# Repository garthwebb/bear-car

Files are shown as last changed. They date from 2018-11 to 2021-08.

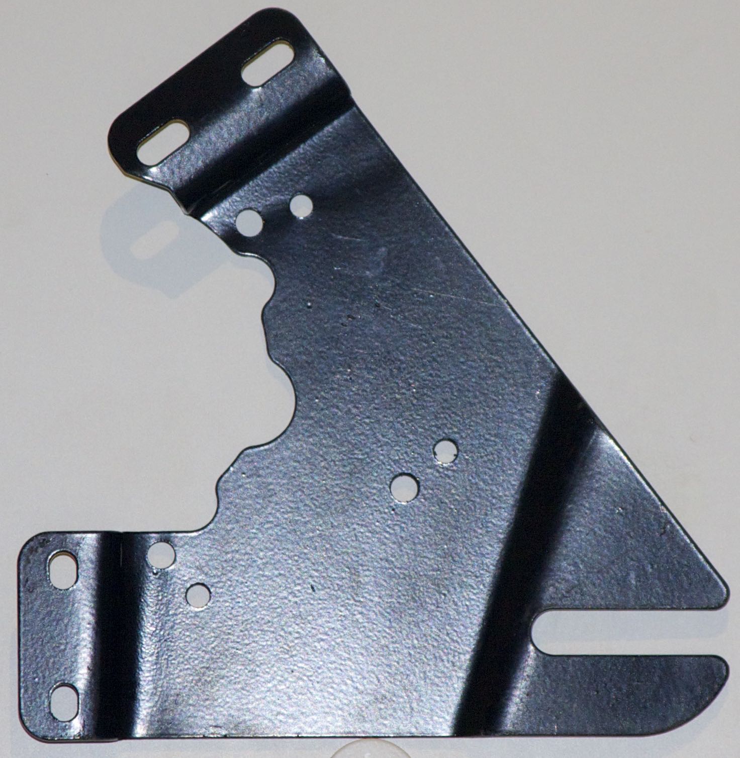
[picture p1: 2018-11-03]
images/IMG_2482.jpg

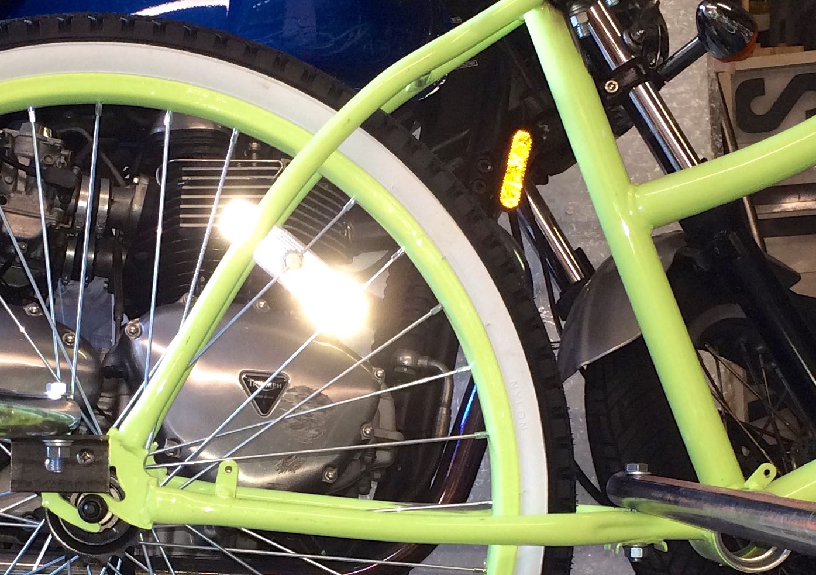
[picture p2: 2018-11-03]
images/IMG_5532.jpg

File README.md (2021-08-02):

# Bear Car

Bear car is an art car project brought to Burning Man in 2015 ([photos](https://photos.app.goo.gl/hQNxJEHgqHZzFq1y2)), meant to look like
[rilakkuma](http://www.san-x.jp/characters/rilakkuma.html), the lazy bear.

It consists of two Huffy beach cruiser bikes that are bolted together.
A linkage in front connects the two bicycles steering columns in an Ackermann steering geometry.  The bicycles are driven by two 350W electric
motors via a chain to the rear wheels.  Two people can ride in the car, who's top speed is around 15mph and can drive for around 2 hours on a charge.

An LED controller connects to a WiFi router that allows an iPhone running [L.E.D Labs](https://apps.apple.com/us/app/l-e-d-lab/id832042156)
to connect and control the dome lights.

bear car

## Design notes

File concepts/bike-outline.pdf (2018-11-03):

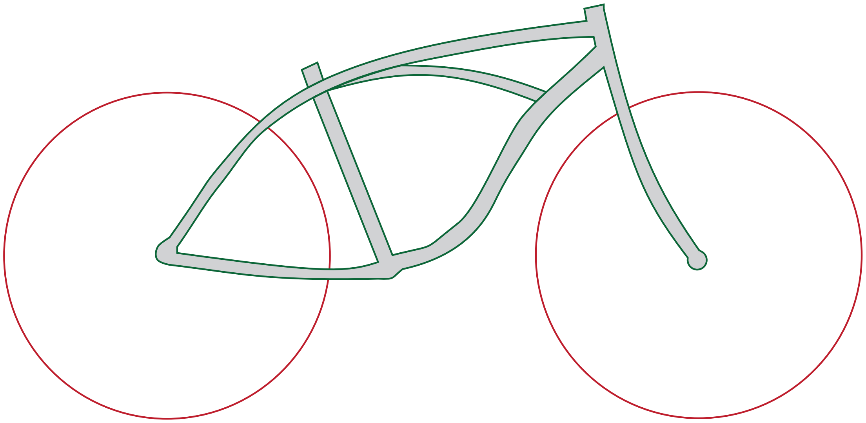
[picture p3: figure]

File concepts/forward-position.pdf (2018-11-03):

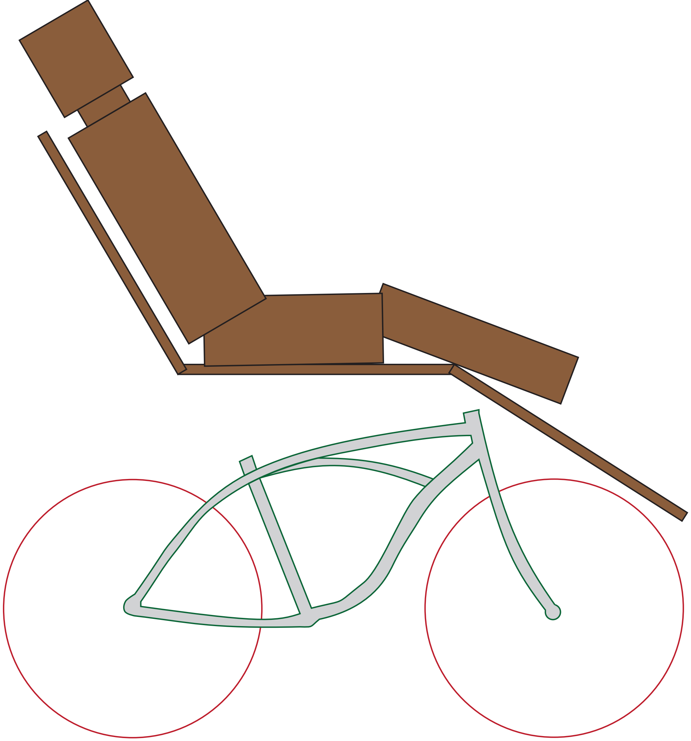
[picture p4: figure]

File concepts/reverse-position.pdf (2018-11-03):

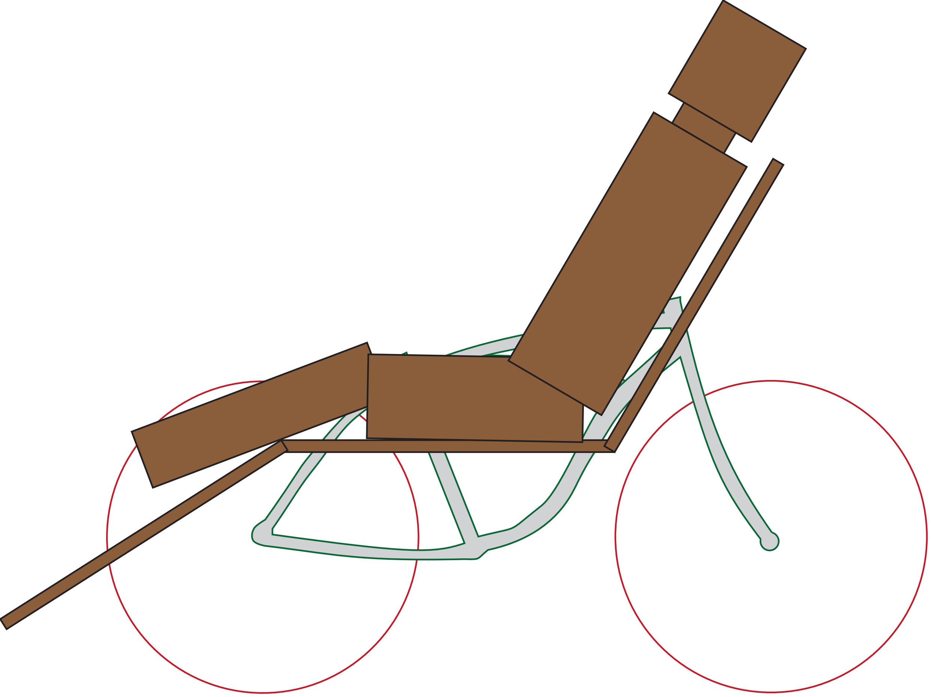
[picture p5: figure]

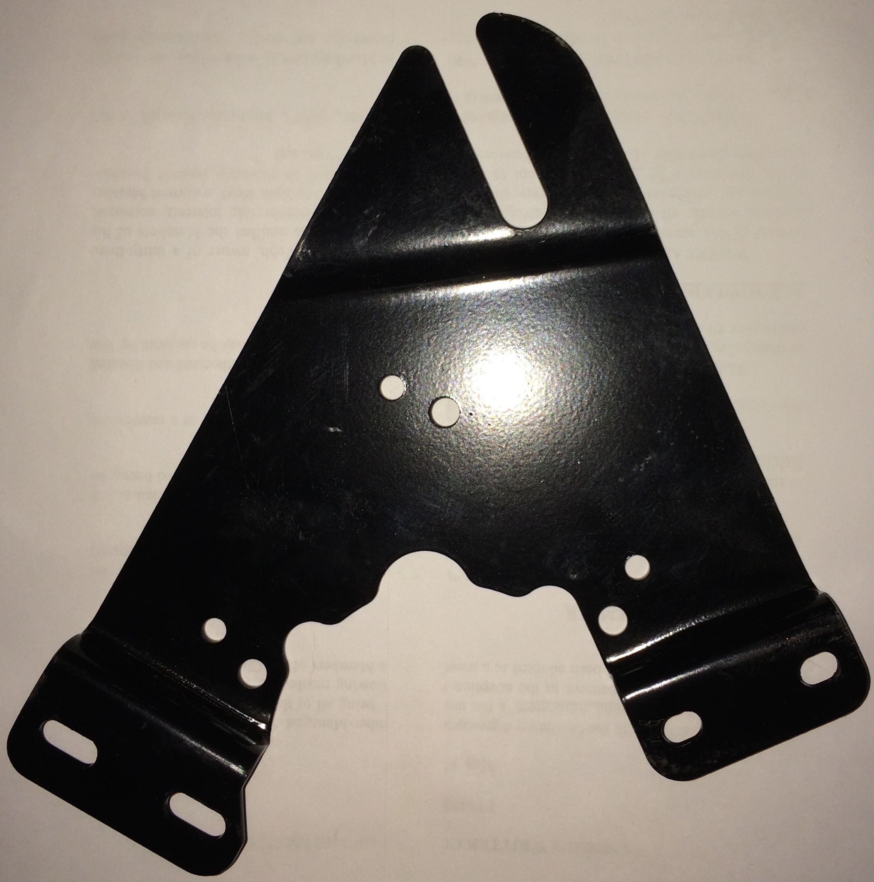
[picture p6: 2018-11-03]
mounting brackets/motor mount.JPG

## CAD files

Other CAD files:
mounting brackets/front fork/Bear Fork Front.dxf
mounting brackets/front fork/Bear Fork Side.dxf
models/Dome.skp
models/Steering Visualization.skp
models/battery holder.skp

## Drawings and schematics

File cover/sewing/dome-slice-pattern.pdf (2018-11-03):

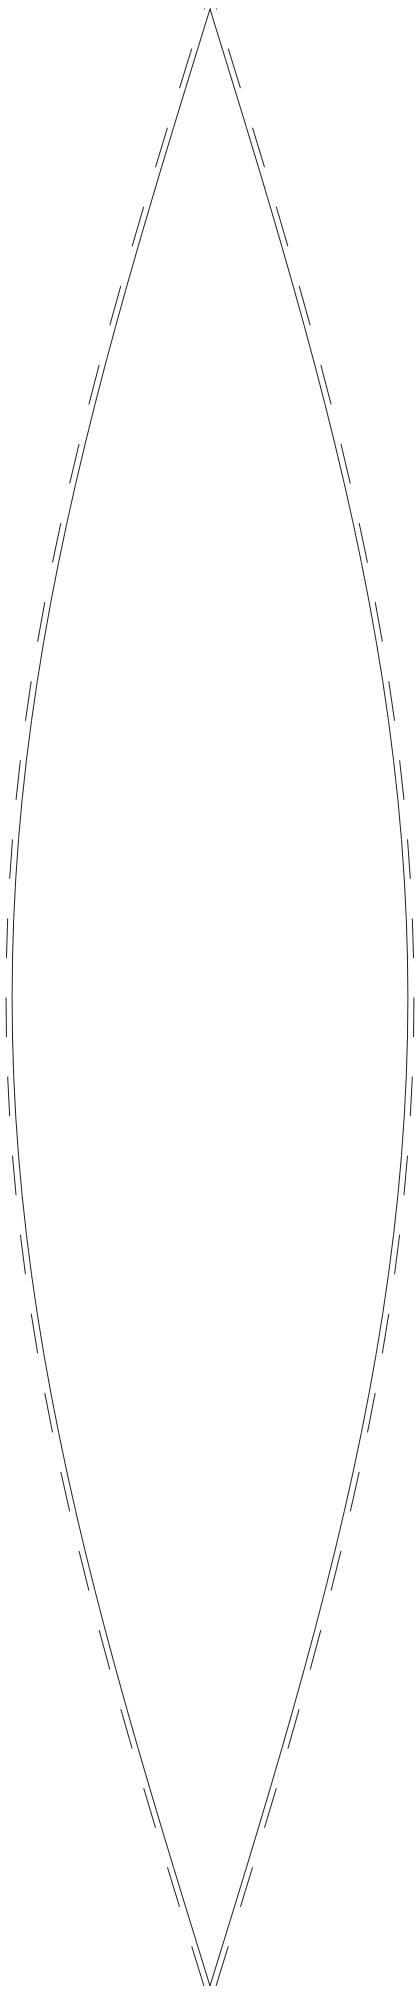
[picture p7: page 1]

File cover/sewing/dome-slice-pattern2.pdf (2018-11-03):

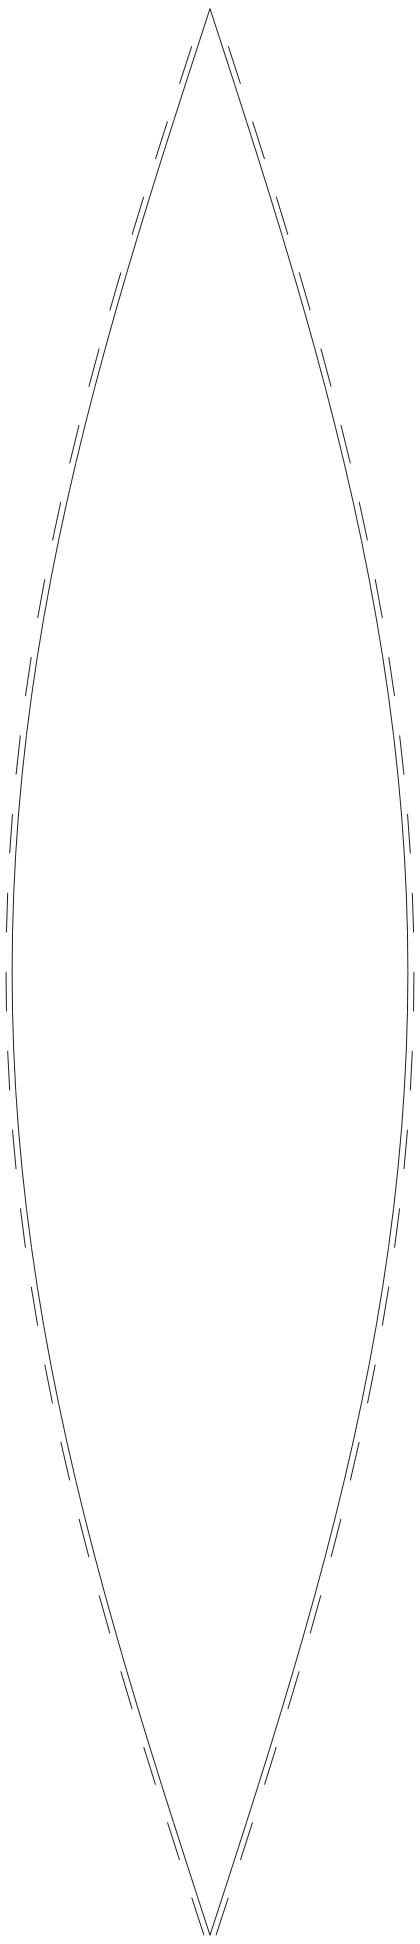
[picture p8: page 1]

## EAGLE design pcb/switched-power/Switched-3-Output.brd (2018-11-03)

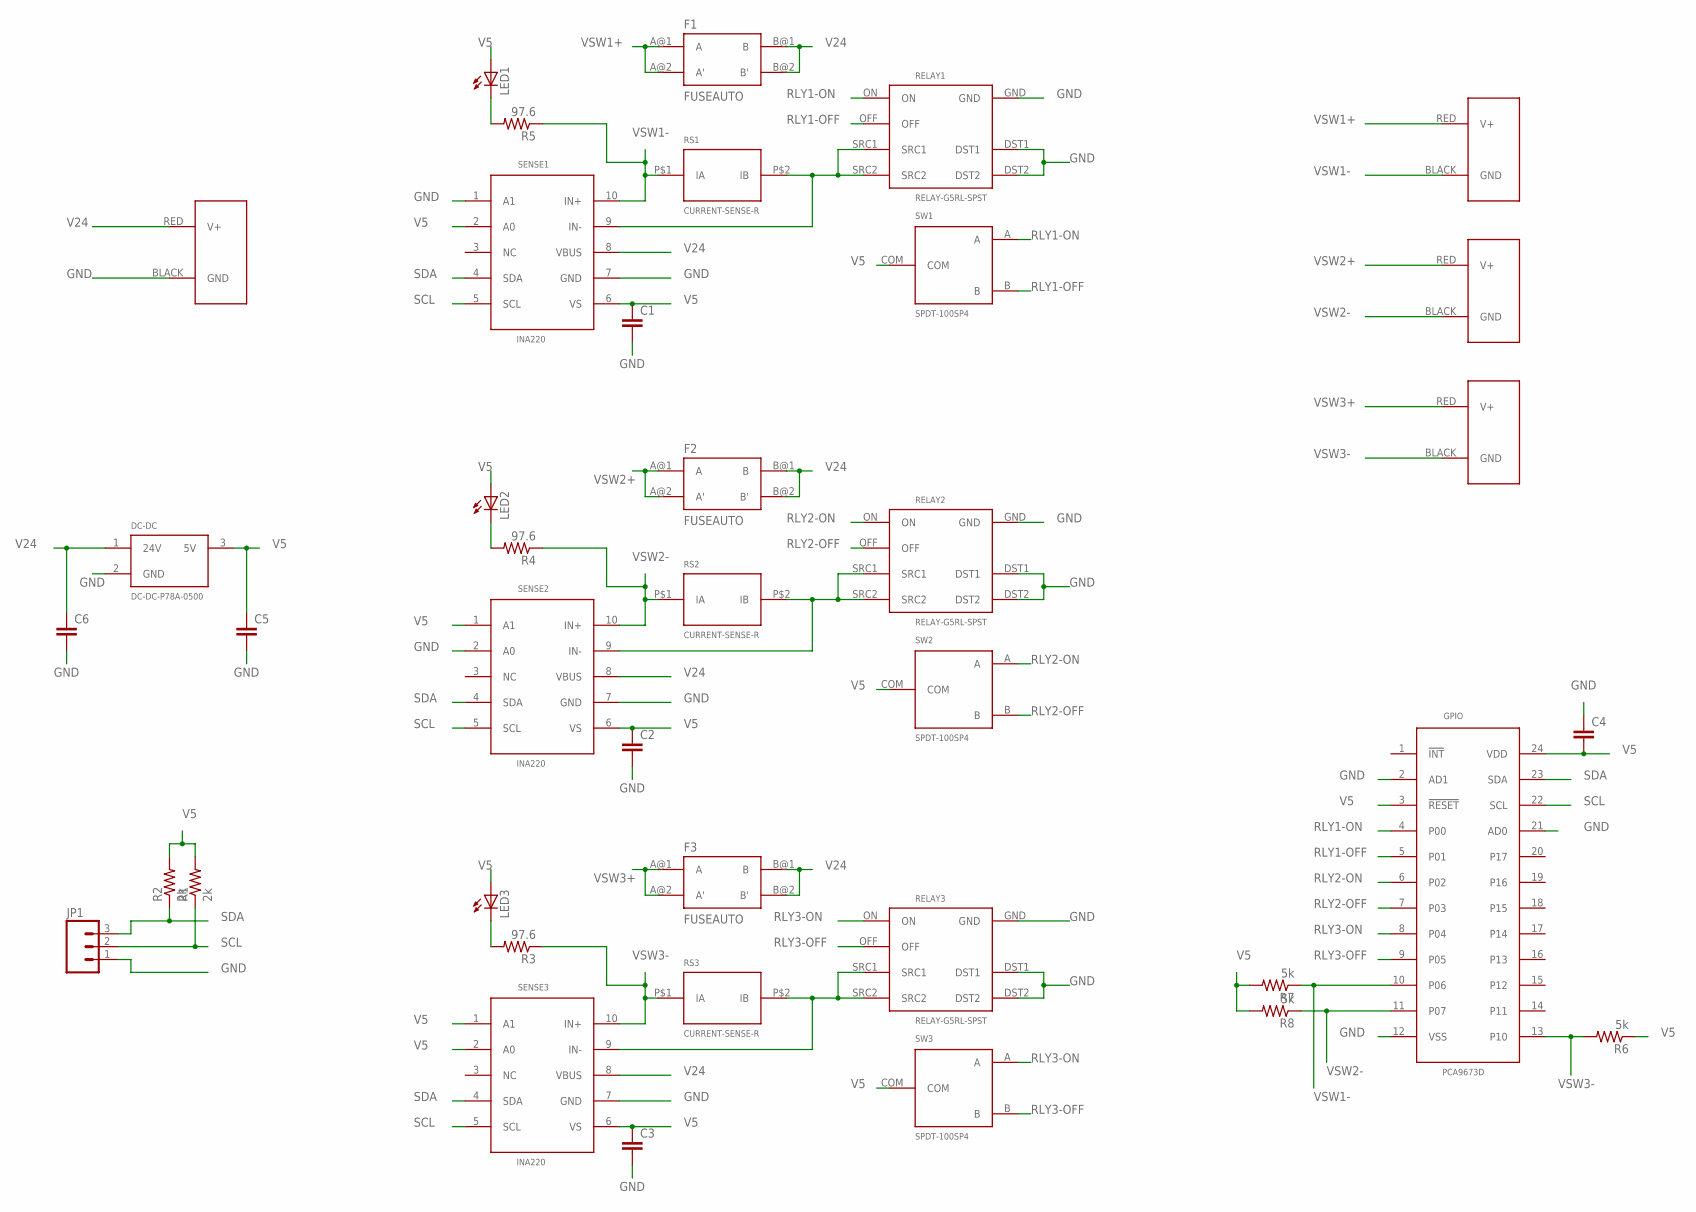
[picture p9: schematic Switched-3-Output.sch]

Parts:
C1, C2, C3, C4, C5, C6: C-EUC0805; C0805
DC-DC: DC-DC-P78A-0500
F1, F2, F3: FUSEAUTO; FUSE
GPIO: PCA9673D; SO24
JP1: M03PTH; 1X03
LED1, LED2, LED3: LED3MM
PWR: POWERPOLE_POWER45A_DRILL; POWERPOLE_PAIR_45A_HOLE
R1, R2: 2k; R0805
R3, R4, R5: 97.6; R0805
R6, R7, R8: 5k; R0805
RELAY1, RELAY2, RELAY3: RELAY-G5RL-SPST
RS1, RS2, RS3: CURRENT-SENSE-R
SENSE1, SENSE2, SENSE3: INA220; SOP-10
SW1, SW2, SW3: SPDT-100SP4
VSW1, VSW2, VSW3: POWERPOLE_POWER45A_DRILL; POWERPOLE_PAIR_45A_HOLE

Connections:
GND: C1.2, C2.2, C3.2, C4.1, C5.2, C6.2, DC-DC.2 (GND), GPIO.2 (AD1), GPIO.12 (VSS), GPIO.21 (AD0), JP1.1, PWR.BLACK (GND), RELAY1.DST1, RELAY1.DST2, RELAY1.GND, RELAY2.DST1, RELAY2.DST2, RELAY2.GND, RELAY3.DST1, RELAY3.DST2, RELAY3.GND, SENSE1.1 (A1), SENSE1.7 (GND), SENSE2.2 (A0), SENSE2.7 (GND), SENSE3.7 (GND)
unnamed: LED1.K (C), R5.2
unnamed: RELAY1.SRC1, RELAY1.SRC2, RS1.P$2 (IB), SENSE1.9 (IN-)
unnamed: RELAY3.SRC1, RELAY3.SRC2, RS3.P$2 (IB), SENSE3.9 (IN-)
unnamed: LED2.K (C), R4.2
unnamed: RELAY2.SRC1, RELAY2.SRC2, RS2.P$2 (IB), SENSE2.9 (IN-)
unnamed: LED3.K (C), R3.2
RLY1-OFF: GPIO.5 (P01), RELAY1.OFF, SW1.B
RLY1-ON: GPIO.4 (P00), RELAY1.ON, SW1.A
RLY2-OFF: GPIO.7 (P03), RELAY2.OFF, SW2.B
RLY2-ON: GPIO.6 (P02), RELAY2.ON, SW2.A
RLY3-OFF: GPIO.9 (P05), RELAY3.OFF, SW3.B
RLY3-ON: GPIO.8 (P04), RELAY3.ON, SW3.A
SCL: GPIO.22 (SCL), JP1.2, R1.1, SENSE1.5 (SCL), SENSE2.5 (SCL), SENSE3.5 (SCL)
SDA: GPIO.23 (SDA), JP1.3, R2.1, SENSE1.4 (SDA), SENSE2.4 (SDA), SENSE3.4 (SDA)
V5: C1.1, C2.1, C3.1, C4.2, C5.1, DC-DC.3 (5V), GPIO.3 (!RESET!), GPIO.24 (VDD), LED1.A, LED2.A, LED3.A, R1.2, R2.2, R6.1, R7.2, R8.2, SENSE1.2 (A0), SENSE1.6 (VS), SENSE2.1 (A1), SENSE2.6 (VS), SENSE3.1 (A1), SENSE3.2 (A0), SENSE3.6 (VS), SW1.COM, SW2.COM, SW3.COM
V24: C6.1, DC-DC.1 (24V), F1.B@1 (B), F1.B@2 (B'), F2.B@1 (B), F2.B@2 (B'), F3.B@1 (B), F3.B@2 (B'), PWR.RED (V+), SENSE1.8 (VBUS), SENSE2.8 (VBUS), SENSE3.8 (VBUS)
VSW1+: F1.A@1 (A), F1.A@2 (A'), VSW1.RED (V+)
VSW1-: GPIO.10 (P06), R5.1, R7.1, RS1.P$1 (IA), SENSE1.10 (IN+), VSW1.BLACK (GND)
VSW2+: F2.A@1 (A), F2.A@2 (A'), VSW2.RED (V+)
VSW2-: GPIO.11 (P07), R4.1, R8.1, RS2.P$1 (IA), SENSE2.10 (IN+), VSW2.BLACK (GND)
VSW3+: F3.A@1 (A), F3.A@2 (A'), VSW3.RED (V+)
VSW3-: GPIO.13 (P10), R3.1, R6.2, RS3.P$1 (IA), SENSE3.10 (IN+), VSW3.BLACK (GND)

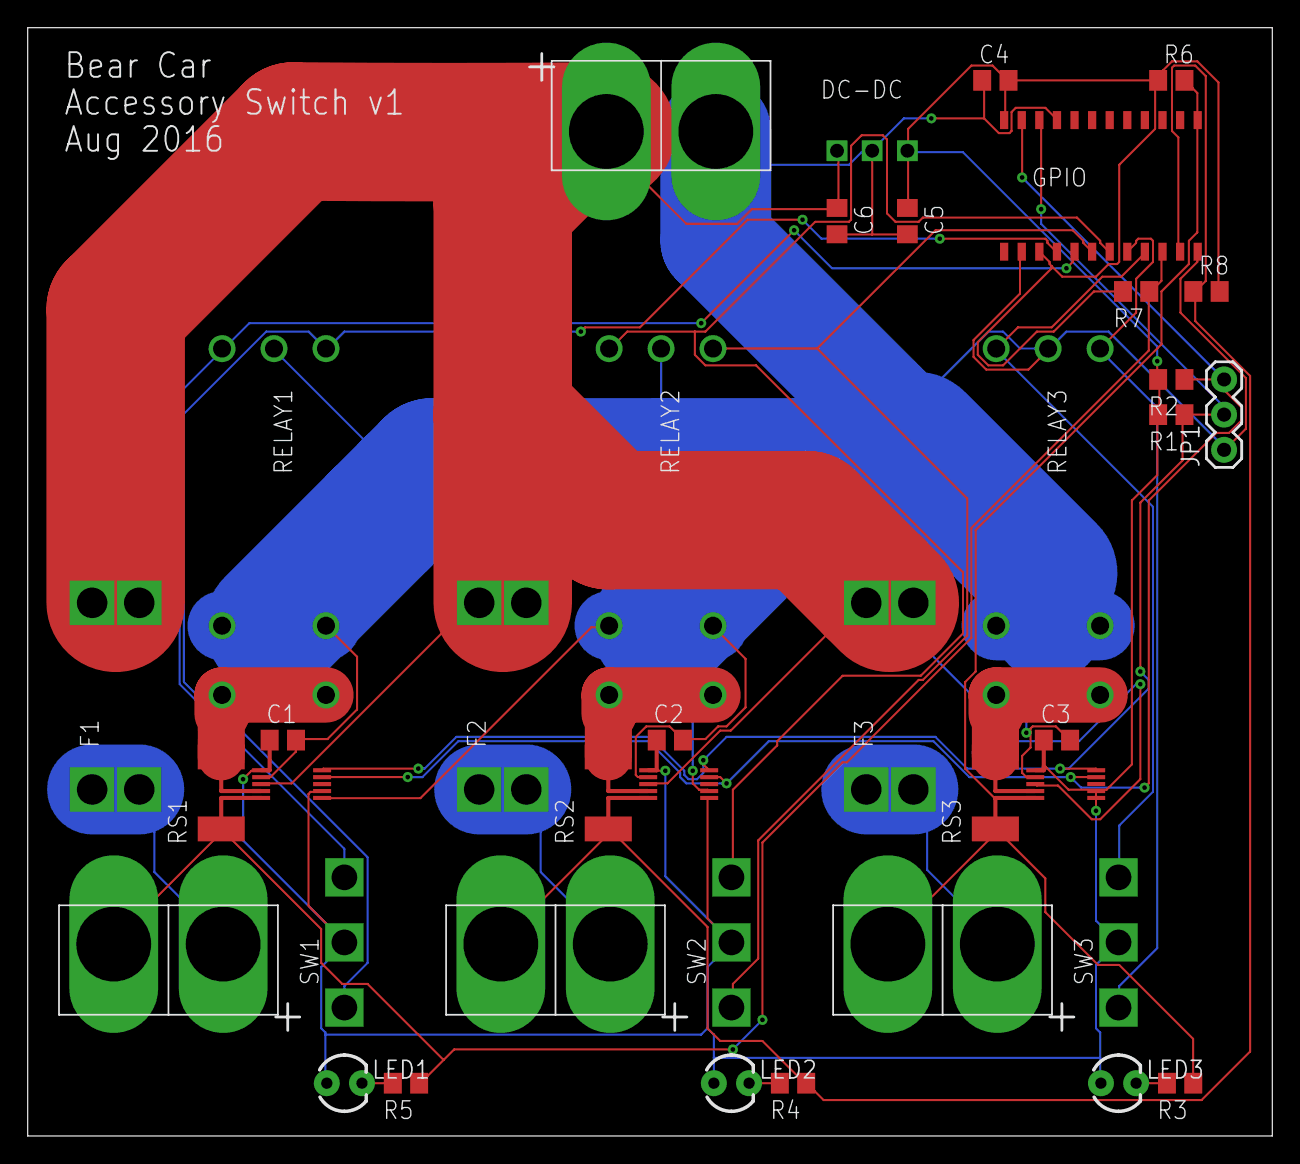
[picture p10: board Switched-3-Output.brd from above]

Board: 2 copper layers, 89.8 x 80.0 mm, 39 parts (0 on the bottom side), 23 nets.

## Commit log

2018-11-03 Add pcb layout stuff first
    [Switched-3-Output.brd, Switched-3-Output.sch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]
2018-11-03 Add gitignore, plus make new revision with latest board
    [Switched-3-Output.brd, Switched-3-Output.sch]
2018-11-03 Remaining design files
    [Bear Fork Front.dxf, Bear Fork Side.dxf, Dome.skp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]
